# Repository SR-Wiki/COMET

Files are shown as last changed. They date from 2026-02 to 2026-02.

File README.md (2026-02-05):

# COMET
This repository includes files for COMET (Cortex-wide Observational Miniature Epifluorescence Technique)
**[[COMET Wiki](https://github.com/ChangliangGuo2/COMET/wiki)] [[Miniscope DAQ Software Wiki](https://github.com/Aharoni-Lab/Miniscope-DAQ-QT-Software/wiki)] [[Miniscope DAQ Firmware Wiki](https://github.com/Aharoni-Lab/Miniscope-DAQ-Cypress-firmware/wiki)]**

## Overview of COMET
<video width="100" height="50" src="https://github.com/user-attachments/assets/f9d4e9b6-175c-49de-b77d-f8bc424e642c"></video>
### Components
<div align=center>
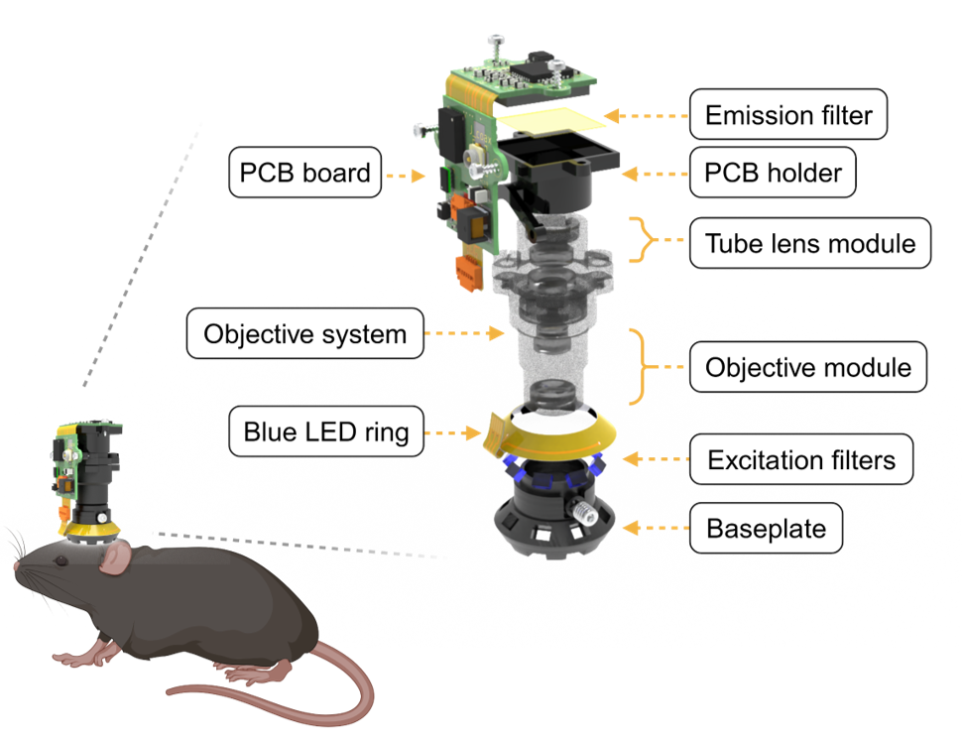
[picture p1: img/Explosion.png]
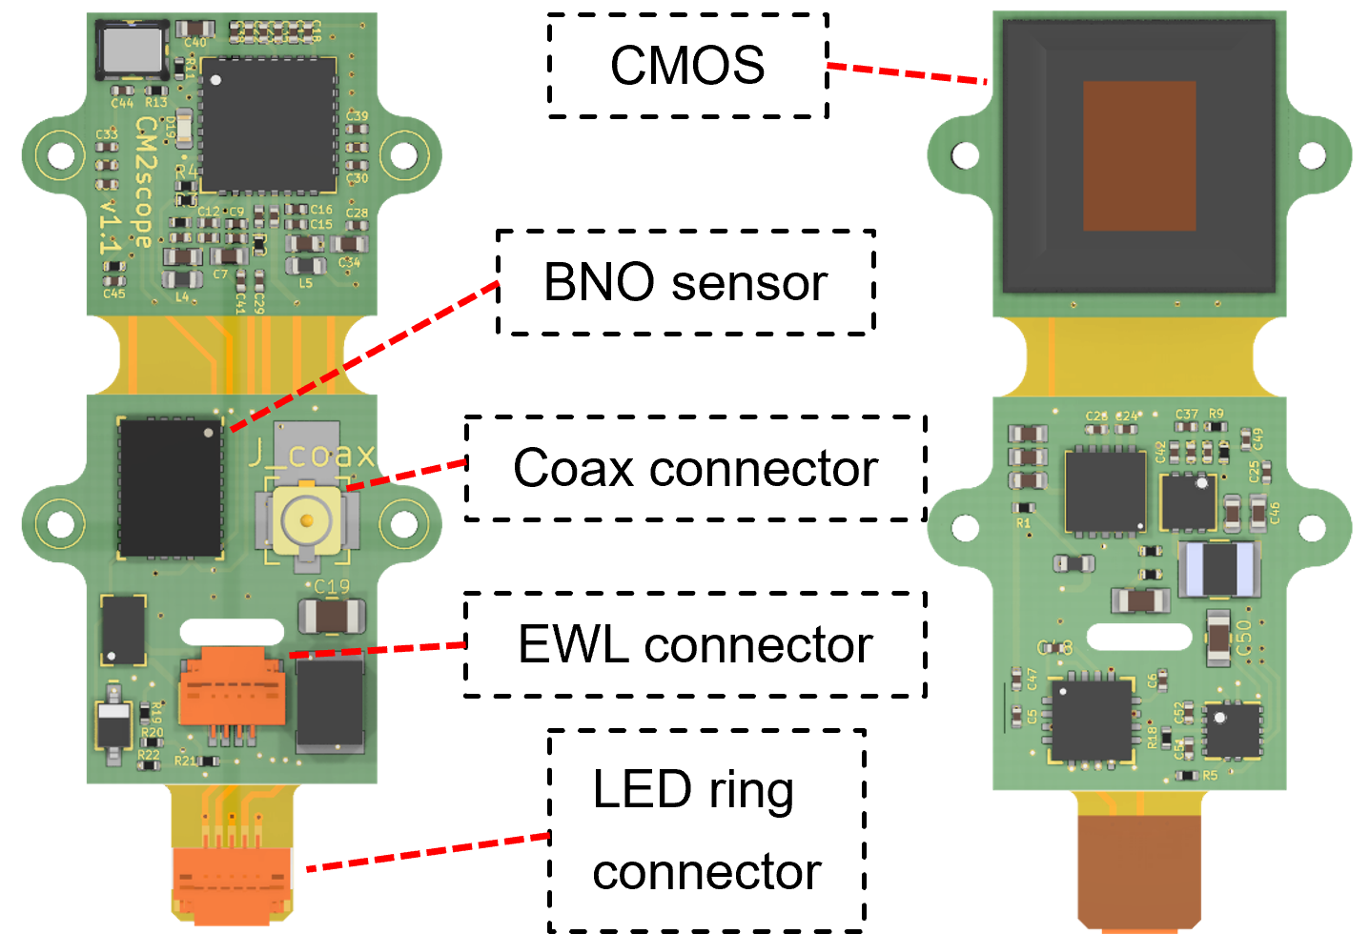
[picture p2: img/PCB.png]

</div>

### Specfications
- **Field of View**: up to 10-mm in diameter
- **Resolution**: single cell_ resolution
- **Working Distance**: ~5mm working distance
- **Illumination**: Optimized led ring excitation for even illuminiation across the field of view
- **Optics**: customized optical system for miniature abberations across the field of view
- **Photo-Bleaching**: _Low photo-bleaching_ even after _two hours of continuous imaging_
- **Weight**: 3.75 grams
- **Impact on Subjects**: Combined with intergrated active commutator(Torque-free),essentially there is _no impact on the free behavior_ of mice even during _two hours_ of continuous imaging
- **Orientation Sensor**: Absolute head orientation sensor
- **Focal Adjustment**: electronic focal adjustment(optional)
- **Imaging Performance**: _stable_ imaging performance even in the _electroshock_ paradigm and  _two hours_ of continuous imaging paradigm
<p dir="auto"><strong>All information, guides, and tutorials can be found on the <a href="https://github.com/ChangliangGuo2/COMET/wiki">COMET Wiki Page</a>.</strong></p>

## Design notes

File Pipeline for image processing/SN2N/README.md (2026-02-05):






<br>



 

<p>
<h1 align="center">SN<font color="#FF6600">2</font>N</h1>
<h5 align="center">Self-inspired learning to denoise for live-cell super-resolution microscopy.</h5>
<h6 align="right">v0.3.5</h6>
</p>

<br>

<p>

</p>
<br>

<br><br><br>

---

## About SN2N

<p>
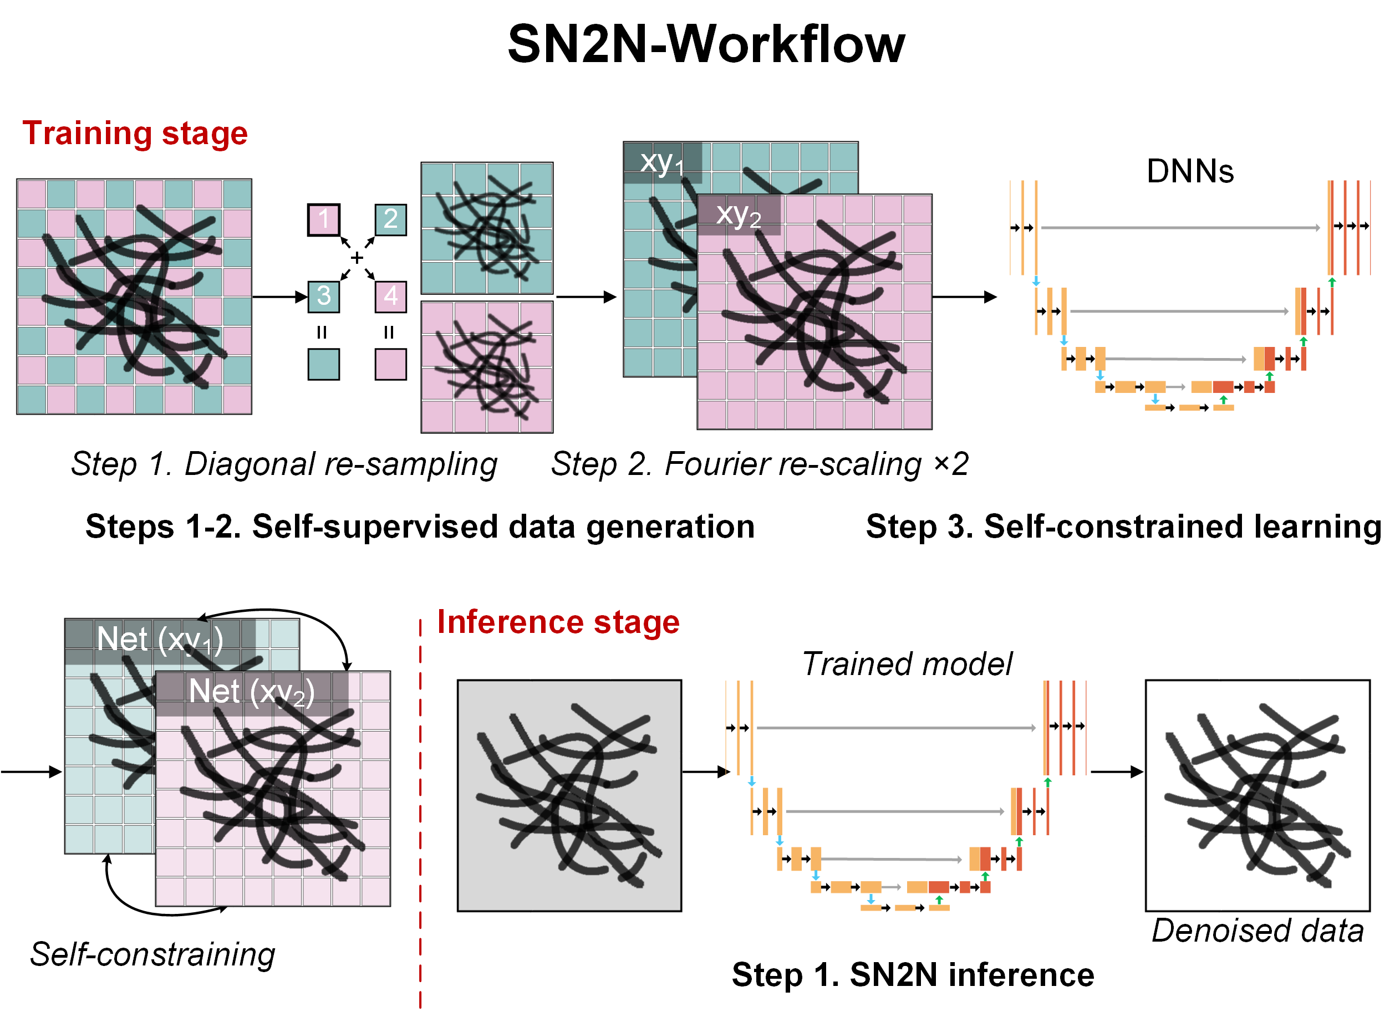
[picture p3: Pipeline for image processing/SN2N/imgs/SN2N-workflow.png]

</p>

SN2N is fully competitive with the supervised learning methods and overcomes the need for large dataset and clean ground-truth, and this is a version specifically for temporal data. **First**, self-supervised data are generated based on images' temporal redundancy, resampling along the T axis. **Second**,  a self-constrained learning process is used to enhance the performance and data-efficiency. **Finally**, a Patch2Patch data augmentation strategy (random patch transformations in multiple dimensions) is designed to further improve the data efficiency.

## 🔧 Installation

### Tested platform
  - Python = 3.7.6, Pytorch = 1.12.0 (`Win 10`, `128 GB RAM`, `NVIDIA RTX 4090 24 GB`, `CUDA 11.6`)

### Dependencies
  - Python >= 3.6
  - PyTorch >= 1.10

### Instruction

1. Alter the working directory.

    ```bash
    cd SN2N    
    ```

2. Create a virtual environment and install PyTorch and other dependencies. Please select the correct Pytorch version that matches your CUDA version from [https://pytorch.org/get-started/previous-versions/](https://pytorch.org/get-started/previous-versions/). 

    Users can set up the environment directly by installing the packages listed in the (**requirements.txt**) file. The packages required by the environment have also been uploaded to the requirements.

    ```bash
    $ conda create -n SN2N python=3.7.6
    $ conda activate SN2N
    
    $ pip install -r requirements.txt
    ```

### How to use?
The SN2N framework contains 3 main steps: self-supervised data generation, model training, and inference, which have been integrated into file SN2N_execute.py. 
```
python SN2N_execute.py --img_path "path/to/raw/data" --P2Pmode "1" --P2Pup "1" --BAmode "1" --SWsize "64" --sn2n_loss "1" --bs "32" --lr "2e-4" --epochs "100"      
```
To see how each part works, this [demo_notebook](./demo_SN2N.ipynb) might be helpful.

#### Parameters instructions

The key parameters are listed below. There are also other parameters that do not require user modification. For a more detailed instructions of parameter setting, please refer to the [official SN2N website](https://github.com/WeisongZhao/SN2N).

```
    -----Parameters------
    =====Important==========

    **Data Generation**
    img_path:
        Path of raw images to train.
    P2Pmode(0 ~ 3):
        Augmentation mode for Patch2Patch.
        0: NONE; 
        1: Direct interchange in t;
        2: Interchange in single frame;
        3: Interchange in multiple frame but in different regions;
        {default: 0}
    P2Pup:
        Increase the dataset to its (1 + P2Pup) times size.
        {default: 0}
    BAmode(0 ~ 2):
        Basic augmentation mode.
        0: NONE; 
        1: double the dataset with random rotate&flip;
        2: eightfold the dataset with random rotate&flip;
        {default: 0} 
    SWsize:
        Interval pixel of sliding window for generating image pathes.
        {default: 64}
    ------------------------------------------------------------------------
    **Model Training**
    sn2n_loss:
        Weight of self-constrained loss.
        {default: 1}
    bs:
        Training batch size.
        {default: 32}
    lr:
        Learning rate
        {default: 2e-4}.
    epochs:
        Total number of training epochs.
        {default: 100}.
    ------------------------------------------------------------------------
    Inference
    final_model:
        if only inference with the final model
        {default: True}.
        
    ======Other parameters do not require modification; ======
    
```

If you have a pretrained model, the inference stage can also be done by:
```
python inference.py --img_path "path/to/raw/data" --model_path "path/to/your/model.pth" --save_path "path/to/save/dir"
```

Several tip:
1. Considering training time, sometimes only parts of raw data might be put into the "raw data" folder.
2. Please ensure that "Users own path/data/raw_data/generated_data" is empty if training data haven't been generated.
3. The sn2n_loss is the most important paramter to finetune, and actually a tradeoff between noise-removal capability and over-smoothing, but a value of 1 will be OK most of the time.
4. Progress can be tracked by checking the validation results in "Users own path/data/raw_data/images/{your_model_name}/images, setting "final_model" to false in the inference stage. In this way, the best model can be manually chosen in case of overfitting (strong artifacts). Nonetheless, ovefitting may also indicate an inappropriate sn2n_loss value.

## &#x1F308; Resources:

- **Some fancy results and comparisons:** [Lab's website](https://weisongzhao.github.io/home/portfolio-4-col.html#SN2N)
- **Preprint:** [Liying Qu et al. Self-inspired learning to denoise for live-cell super-resolution microscopy, bioRxiv (2024).](https://doi.org/10.1101/2024.01.23.576521)
- **Detailed Instructions:** https://github.com/WeisongZhao/SN2N
- **Publication:** [Liying Qu et al. Self-inspired learning for denoising live-cell super-resolution microscopy, 21, 1895–1908, Nature Methods (2024)](https://www.nature.com/articles/s41592-024-02400-9).

## Open source [SN2N](https://github.com/WeisongZhao/SN2N)
This software and corresponding methods can only be used for **non-commercial** use, and they are under Open Data Commons Open Database License v1.0.

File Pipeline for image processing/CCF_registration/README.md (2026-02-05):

# Registering each extracted neuron to the CCF atlas
## Parameters：
- front_pos：cranial window Anterior edge to the brgma point _(unit:mm)_
- back_pos：cranial window Posterior edge to the brgma point _(unit:mm)_
- RSPd_MO_point： Displacement adjustment between the standard brain and the FOV of the image;example:[vertical_displacement，horizotal_displacement] _(unit:pixel)_
- angle：rotate angle, clockwise is negtive _(unit:°)_
- instrument_pixel_size：optical instrument pixel size _(unit:mm/pixel)_
- instrument_size：captured image size,example:[1944,1944] _(unit:pixel)_
## How to use cortical_mapping_CM2.m：
Fill in `front_pos`, `back_pos`, `instrument_pixel_size`   `instrument_size` parameters based on the actual surgical conditions and optical equipment parameters.
Then, initially set the endpoint after line 65, iteratively run the program and modify the `RSPd_MO_point` and `angle` parameters until the drawn brain map matches the actual data. 
Once the parameters are set, remove the breakpoint and run the program entirely.
## Result：
<div align=center>

</div>

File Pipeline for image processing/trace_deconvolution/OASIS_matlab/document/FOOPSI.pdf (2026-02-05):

# Brief summary of the deconvolution problem

A brief summary of denoising and deconvolving calcium imaging data using FOOPSI approaches.

# FOOPSI

A general form of the FOOPSI problem

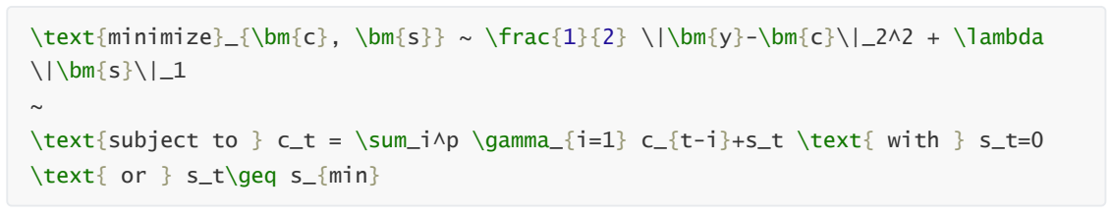
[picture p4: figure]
\text{ or } s_t\geq s_{min}

where $|\cdot|1$ means L-1 norm (http://mathworld.wolfram.com/L1-Norm.html) and $|\cdot|2$ means L-2 norm. (http://mathworld.wolfram.com/L2-Norm.html) $\bm{y}$ is the noisy raw calcium trace and $\bm{c}$ is the desired denoised trace. We use an auto-regressive (AR) $c_t = \sum_i^p \gamma{i=1} c{t-i}+s_t$ model to model $\bm{c}$ and the corresponding spiking activity $\bm{s}$. A more general model of $\bm{c}$ and $\bm{s}$ is $\bm{c} = \bm{s} \ast \bm{h}$, where $\ast$ means convolution. The convolution kernel $\bm{h}$ has a interpretation of calcium responses of a neuron after firing a spike.

The AR model is equivalent to special kernel $\bm{h}$. For example, AR-1 model ($p=1$) correspond to

and AR-2 ($p=2$) model correspond to

Details of these AR model can be found in the literatures [1][2][3].

# Different formulations of FOOPSI

We described the most general format of FOOPSI above. In practice, people use different formulations of FOOPSI for their own data. Here I brief summarize different formulations.

## original FOOPSI [1]

The original FOOPSI solves the following problem

where $\lambda$ has to be pre-specified by users and $\gamma$ needs to be estimated as well.

This formulation has the simplest format, but the parameter selection is a pain.

\text{minimize}_{\bm{c}, \bm{s}} ~ \frac{1}{2} \|\bm{y}-\bm{c}\|_2^2 + \lambda

\text{subject to } c_t = \sum_i^p \gamma_{i=1} c_{t-i}+s_t \text{ with } s_t=0

h(t) = \exp(-t/\tau)

h(t) = \exp(-t/\tau_d) - \exp(-t/\tau_r).

\text{minimize}_{\bm{c}, \bm{s}} ~ \frac{1}{2} \|\bm{y}-\bm{c}\|_2^2 + \lambda

\text{subject to } c_t = \sum_i \gamma_{i=1}^p c_{t-i}+s_t

## constrained FOOPSI [2]

This formulation is equivalent to solving a original FOOPSI problem except that it chooses $\lambda$ automatically by constraining the residual sum of squares (RSS) to be $\sigma^2T$, where $\sigma$ is the noise level and can be estimated from the raw data.

### thresholded FOOPSI [3]

Both the upper two approaches uses L-1 penalty to enforce the sparsity of the spiking signal $\bm{s}$. The advantage of these two formulations is that the optimization problems are convex. However, the estimated $\bm{s}$ usually contains many false positive spikes with small amplitudes, and these false positives affect the accurate estimation of the amplitudes of those true spikes. We can definitely remove them by thresholding $\hat{\bm{s}}$ in the downstream analysis, but it won't help with the estimation of true spikes in this step.

Thus a thresholded-FOOPSI was proposed to integrate the thresholding step into deconvolution by setting a hard threshold of spike size $s{min}$. This $s{min}$ is usually chosen as $3\sigma$, where the noise level $\sigma$ is estimated from the raw data.

This other automatic way of choosing $s_{min}$ is to use a similar approach of constrained FOOPSI by letting RSS equal to $\sigma^2T$.

## why OASIS

FAST and ONLINE

For the original FOOPSI and the constrained FOOPSI problem, they were usually solved using generic convex optimiation solvers to solve, which is slow and has to use the complete time series of $\bm{y}$ to optimize. OASIS is optimized for solving FOOPSI problems by utilizing the special structure of AR model. The algorithm is FAST and, more importantly, it allows ONLINE processing of the data.

As for the thresholded FOOPSI, it is not convex. Thus we don't have algorithm to solve this problem at the beginning. When OASIS was developed, we made very tiny changes to the code and it outputs reasonable good results. Also there is no guarantee on the global optimums, the results are usually good in both simulated data and real data.

Besides solving the above optimization problems, the implementation of OASIS also include supports for automatic optimizing parameters in those problems, such as $\lambda, \gamma$ and the baseline $b$.

\text{subject to } c_t = \sum_i \gamma_{i=1}^p c_{t-i}+s_t \text{ and } \|\bm{y}-

\text{subject to } c_t = \sum_i \gamma_{i=1}^p c_{t-i}+s_t \text{ with } s_t=0

## References

[1] Vogelstein, J.T., Packer, A.M., Machado, T.A., Sippy, T., Babadi, B., Yuste, R. and Paninski, L., 2010. Fast nonnegative deconvolution for spike train inference from population calcium
imaging. Journal of neurophysiology,104(6), pp.3691-3704.
[2] Pnevmatikakis, E.A., Soudry, D., Gao, Y., Machado, T.A., Merel, J., Pfau, D., Reardon, T., Mu, Y., Lacefield, C., Yang, W. and Ahrens, M., 2016. Simultaneous denoising, deconvolution, and demixing of calcium imaging data. Neuron, 89(2), pp.285-299.
[3] Friedrich, J., Zhou, P. and Paninski, L., 2017. Fast online deconvolution of calcium imaging data. PLoS computational biology, 13(3), p.e1005423.

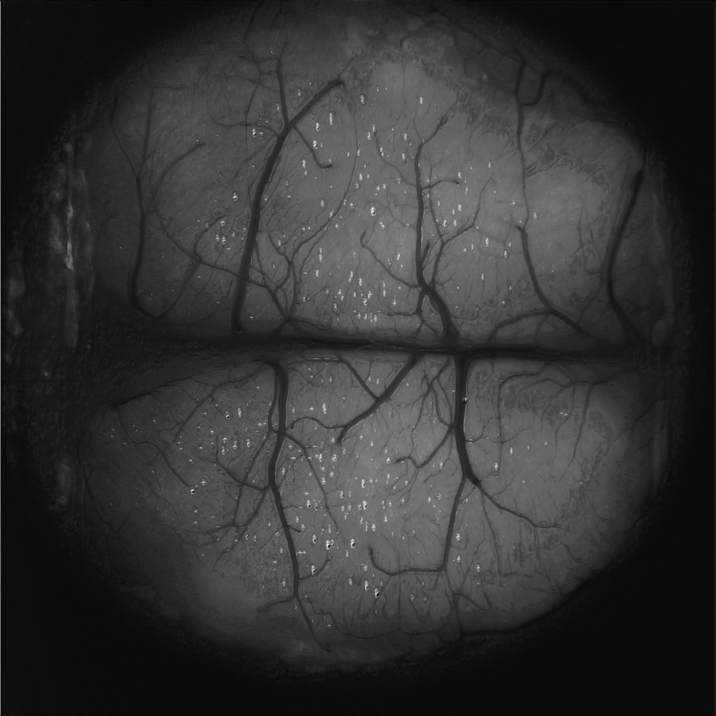
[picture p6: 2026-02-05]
Pipeline for image processing/SN2N/example/rawdata/images/Neuron__EPOCH50_BS64_LOSSconsis_1.50_LOSSsparse0.00_/images/epoch_49.tif

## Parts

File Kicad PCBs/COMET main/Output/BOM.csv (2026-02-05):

Item | Qty | Reference(s) | Value | Footprint | Description | Note
1 | 6 | C1, C2, C14, C20, C34, C40 | GRM155R60J106ME15D | .Capacitor:C_0402_1005Metric_L | CAP CER 10UF 6.3V X5R 0402 | 10uF
3 | 1 | C4 | GRM033R61C473KE84D | .Capacitor:C_0201_0603Metric_L | CAP CER 0.047UF 16V X5R 0201 | 0.047uF
4 | 4 | C5, C6, C47, C48 | GRM033R61A225ME47D | .Capacitor:C_0201_0603Metric_L | CAP CER 2.2UF 10V X5R 0201 | 2.2uF
5 | 3 | C7, C10, C46 | GRM155R60J475ME87D | .Capacitor:C_0402_1005Metric_L | CAP CER 4.7UF 6.3V X5R 0402 | 4.7uF
7 | 7 | C9, C12, C16, C18, C23, C42, C44 | GRM033R71A103KA01D | .Capacitor:C_0201_0603Metric_L | CAP CER 10000PF 10V X7R 0201 | 10nF
10 | 1 | C19 | GRM21BR61A476ME15L | .Capacitor:C_0805_2012Metric_L | CAP CER 47UF 10V X5R 0805 | 47uF
12 | 1 | C21 | GRM158C80G226ME01J | .Capacitor:C_0402_1005Metric_L |  | 22uF
13 | 7 | C13, C24, C25, C26, C28, C38, C45 | GRM033R61A105ME15D | .Capacitor:C_0201_0603Metric_L | CAP CER 1UF 10V X5R 0201 | 1uF
16 | 21 | C3, C8, C11, C15, C17, C22, C27, C29, C30, C31, C32, C33, C35, C36, C37, C39, C41, C43, C49, C51, C52 | GRM033R61A104ME15D | .Capacitor:C_0201_0603Metric_L | CAP CER 0.1UF 10V X5R 0201 | 0.1uF
23 | 1 | C50 | GRJ188R72A104KE11D | .Capacitor:C_0603_1608Metric_L | CAP CER 0.1UF 100V X7R 0603 | 100nF
26 | 1 | D18 | BAS316-TP | .Diode:SOD_323_250X125X110L30X32L | DIODE GEN PURP 100V 250MA SOD323
27 | 1 | D19 | LED 0402 | LED_SMD:LED_0402_1005Metric | LED RED 0402 SMD | red
28 | 1 | J1 | FH19C-5S-0.5SH(10) | .FH19C-4S-0.5SH(10):FH19C-5S-0.5SH(10)
29 | 1 | J4 | FH19C-4S-0.5SH(10) | .FH19C-4S-0.5SH(10):FH19C-4S-0.5SH(10)
31 | 1 | J_coax1 | U.FL-R-SMT-1(10) | .Connector:Coax_Conn_U.FL | CONN U.FL RCPT STR 50 OHM SMD
33 | 3 | L1, L4, L5 | BLM15HD102SN1D | Inductor_SMD:L_0402_1005Metric | FERRITE BEAD 1 KOHM 0402 1LN | 1kohm
34 | 1 | L2 | ADL3225V-470MT-TL000 | .Inductor:L_1210_3225Metric_L | FIXED IND 47UH 500MA 900 MOHM | 47uH
35 | 1 | L3 | LQM18PN3R3MGHD | .Inductor:L_0603_1608Metric_L | FIXED IND 3.3UH 1.05A 250 MOHM | 3.3uH
36 | 1 | L6 | LQM2HPN1R0MG0 | .Inductor:L_1008_2520Metric_L
37 | 1 | R1 | ERJ-1GNF1801C | .Resistor:R_0201_0603Metric_ERJ_L | RES SMD 1.8K OHM 1% 1/20W 0201 | 1.8k
38 | 1 | R2 | ERJ-1GNF49R9C | .Resistor:R_0201_0603Metric_ERJ_L | RES SMD 49.9 OHM 1% 1/20W 0201 | 49.9
39 | 4 | R3, R7, R9, R10 | ERJ-1GNF1022C | .Resistor:R_0201_0603Metric_ERJ_L | RES SMD 10.2K OHM 1% 1/20W 0201 | 10.2k
40 | 1 | R4 | ERJ-1GNF1003C | .Resistor:R_0201_0603Metric_ERJ_L | RES SMD 100K OHM 1% 1/20W 0201 | 100k
41 | 1 | R5 | 0402WGF6491TCE | .Resistor:R_0201_0603Metric_ERJ_L | RES SMD 10.2K OHM 1% 1/20W 0201 | 6.49k
44 | 1 | R12 | 1k | .Resistor:R_0201_0603Metric_ERJ_L | 1k | 1k
45 | 1 | R13 | 500 | .Resistor:R_0201_0603Metric_ERJ_L | 500 | 500
46 | 2 | R14, R15 | ERJ-1GNF3321C | .Resistor:R_0201_0603Metric_ERJ_L | RES SMD 3.32K OHM 1% 1/20W 0201 | 3.32k
47 | 1 | R18 | 0402WGF1962TCE | .Resistor:R_0201_0603Metric_ERJ_L | RES SMD 10.2K OHM 1% 1/20W 0201 | 19.6k
48 | 2 | R19, R21 | ERJ-1GNJ622C | .Resistor:R_0201_0603Metric_ERJ_L | RES SMD 6.2K OHM 5% 1/20W 0201 | 6.2k
49 | 2 | R20, R22 | ERJ-1GNF3741C | .Resistor:R_0201_0603Metric_ERJ_L | RES SMD 3.74K OHM 1% 1/20W 0201 | 3.74k
50 | 1 | U1 | DS90UB913ATRTVTQ1 | .Package_QFN:QFN_33_P50_500X500X80L40X24T310L | IC SER/DES 10-100MHZ FPD 32WQFN
51 | 1 | U2 | LTC3217EUD_TRPBF | Package_DFN_QFN:HVQFN-16-1EP_3x3mm_P0.5mm_EP1.5x1.5mm | \n600mA Low Noise Multi-LED Camera Light Charge Pumps\n
52 | 1 | U3 | SC189ZULTRT | .Package_SON:SON_7P50_200X200X57L35X24T170X80N
53 | 1 | U4 | NCV8154MW180280TBG | .Package_QFN:DFN10_3x3_11P50_300X300X100L40X24T250X180N
54 | 1 | U5 | BNO055 | Package_LGA:LGA-28_5.2x3.8mm_P0.5mm | IMU ACCEL/GYRO/MAG I2C 28LGA
55 | 1 | U6 | SG-210STF 66.6667ML3 | .Oscillator:OSC_CC250X200X80L70X75L | XTAL OSC XO 66.6667MHZ CMOS SMD
56 | 1 | U7 | MAX14574EWL+ | .Package_BGA:BGA_15_NP50_3X5_155X255X69B31N | 4-Channel, High-Voltage, Liquid Lens Driver
57 | 1 | U8 | MT9P031I12STM-DP | .Package_LCC:iLCC48P70_1000X1000X135L80X40N | SENSOR IMAGE 5MP MONO CMOS 48LCC
58 | 1 | U9 | TPL0102-100RUCR | .Package_QFN:QFN_14_P40_200X200X40L40X20L | IC DGT POT 100KOHM 256TAP 14QFN

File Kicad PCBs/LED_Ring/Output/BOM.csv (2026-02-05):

Item | Qty | Reference(s) | Value | Footprint | Description | Note
1 | 8 | D1, D2, D3, D4, D5, D6, D7, D8 | LXZ1-PB01 | LXZ1-PB01 | LED LUXEON Z BLUE 470NM SMD | Blue

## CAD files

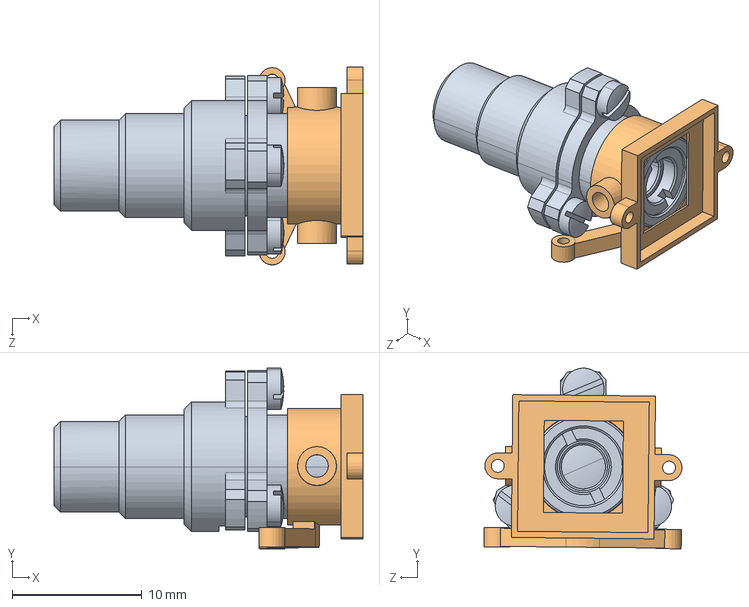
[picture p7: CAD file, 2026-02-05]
3D printed bodies/CMOS cover/装配体1.SLDASM
23.8 x 13.9 x 15.3 mm
Microscope-00.step
cmos外壳v5

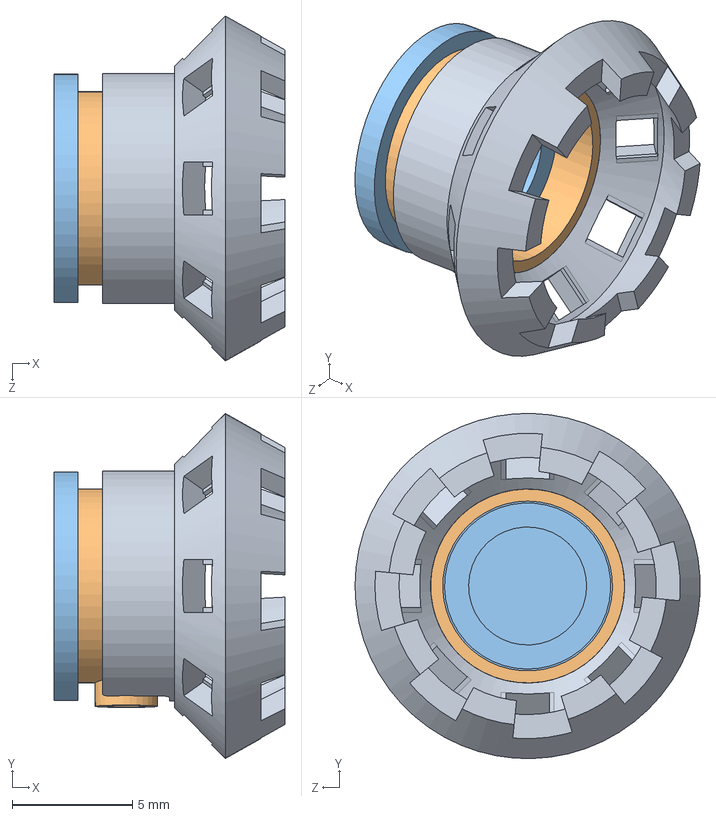
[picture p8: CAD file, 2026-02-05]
3D printed bodies/LED Ring Holder and Baseplate/45°/sldprt/LXZ1-PB01_num8_45°_6mm_v3加铝环/装配体1.SLDASM
9.59 x 14.3 x 14.3 mm
下面3D打印部分
铝环
protective_cap

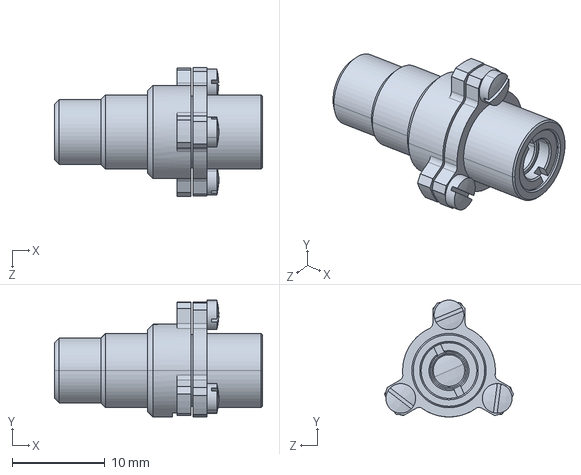
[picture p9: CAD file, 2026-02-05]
3D printed bodies/CMOS cover/Microscope-00.STEP
22.4 x 12.6 x 13.9 mm

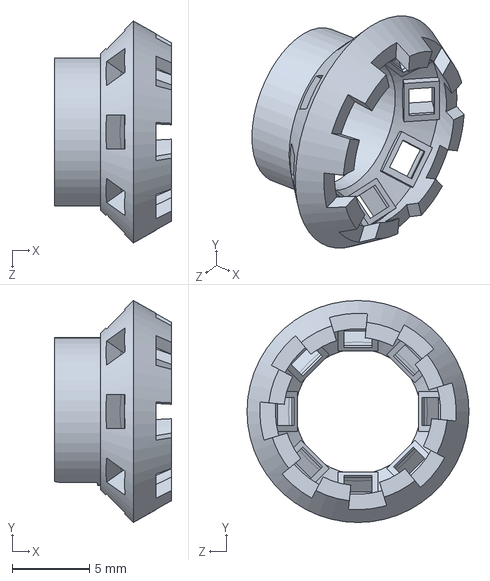
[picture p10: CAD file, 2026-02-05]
3D printed bodies/LED Ring Holder and Baseplate/45°/sldprt/LXZ1-PB01_num8_45°_6mm_v3加铝环/led_ring_illumination_加铝环_加深槽.SLDPRT
7.59 x 14.3 x 14.3 mm

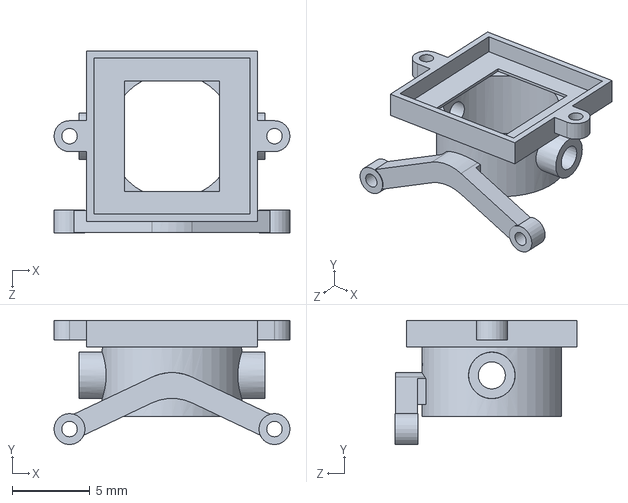
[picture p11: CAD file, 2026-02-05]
3D printed bodies/CMOS cover/cmos外壳v5.SLDPRT
15.2 x 8.00 x 11.8 mm

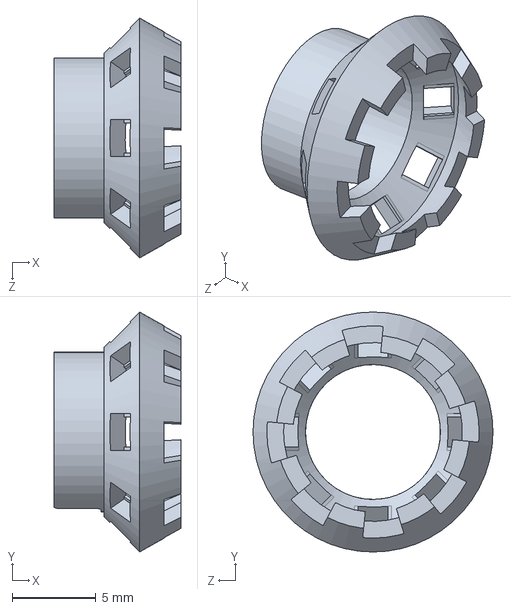
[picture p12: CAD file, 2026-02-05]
3D printed bodies/LED Ring Holder and Baseplate/45°/sldprt/LXZ1-PB01_num8_45°_6mm_v3加铝环/下面3D打印部分.SLDPRT
7.59 x 14.3 x 14.3 mm

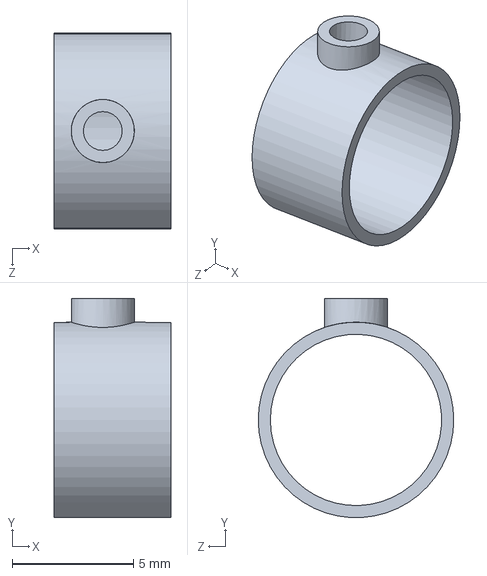
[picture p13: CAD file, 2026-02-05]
3D printed bodies/LED Ring Holder and Baseplate/45°/sldprt/LXZ1-PB01_num8_45°_6mm_v3加铝环/铝环.SLDPRT
4.80 x 9.02 x 8.05 mm

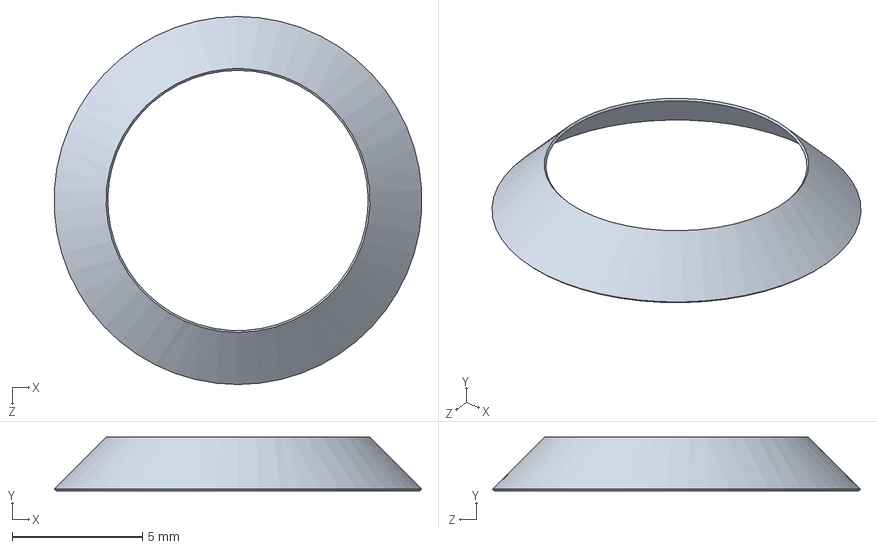
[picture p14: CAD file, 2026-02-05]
3D printed bodies/LED Ring Holder and Baseplate/45°/sldprt/LXZ1-PB01_num8_45°_6mm_v3加铝环/fpc.SLDPRT
14.1 x 2.07 x 14.1 mm

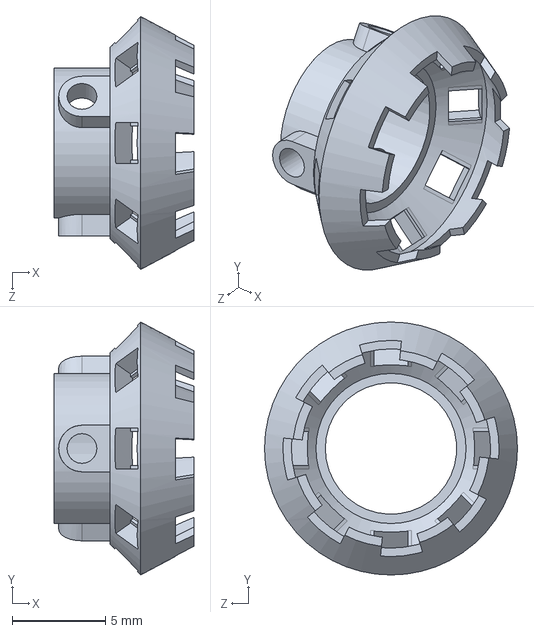
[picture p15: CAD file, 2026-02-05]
3D printed bodies/LED Ring Holder and Baseplate/45°/sldprt/LXZ1-PB01_num8_45°_6mm_v3加铝环/LXZ1-PB01_num8_45°_6mm_v3加铝环.SLDPRT
7.51 x 13.6 x 13.6 mm

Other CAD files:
3D printed bodies/CMOS cover/cmos外壳v5.STL

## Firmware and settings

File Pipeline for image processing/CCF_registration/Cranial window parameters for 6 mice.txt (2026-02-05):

AR93    Bregma至前沿 3.0mm，Bregma至后沿 4.5mm
AR94    Bregma至前沿 3.0mm，Bregma至后沿 4.4mm
AR367   Bregma至前沿 3.0mm，Bregma至后沿 4.8mm
AR369   Bregma至前沿 3.0mm，Bregma至后沿 5.0mm
AR370   Bregma至前沿 2.8mm，Bregma至后沿 5.0mm
AR371   Bregma至前沿 3.0mm，Bregma至后沿 4.8mm

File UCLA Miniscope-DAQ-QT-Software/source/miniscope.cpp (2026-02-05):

#include "miniscope.h"
#include "newquickview.h"
#include "videodisplay.h"
#include "videodevice.h"

#include <QQuickView>
#include <QQuickItem>
#include <QSemaphore>
#include <QObject>
#include <QTimer>
#include <QAtomicInt>
#include <QJsonObject>
#include <QJsonDocument>
#include <QJsonArray>
#include <QQmlApplicationEngine>
#include <QVector>
#include <QString>
#include <QtMath>
#include <QSerialPort>
#include <QSerialPortInfo>
#include <cmath>
#include <QtGlobal>



Miniscope::Miniscope(QObject *parent, QJsonObject ucDevice, qint64 softwareStartTime) :
    VideoDevice(parent, ucDevice, softwareStartTime),
    baselineFrameBufWritePos(0),
    baselinePreviousTimeStamp(0),
    m_displatState("Raw"),
    m_softwareStartTime(softwareStartTime)
{

    // --------------------

    // For Neuron Trace Display
    m_numTraces = 0;
    m_traceLastValueIdx = 0;
    // --------------------

    m_ucDevice = ucDevice; // hold user config for this device
    m_cDevice = getDeviceConfig(m_ucDevice["deviceType"].toString());

//    QObject::connect(this, &VideoDevice::displayCreated, this, &Miniscope::displayHasBeenCreated);
//    QObject::connect(this, &Miniscope::displayCreated, this, &Miniscope::displayHasBeenCreated);

}
void Miniscope::setupDisplayObjectPointers()
{
    // display object can only be accessed after backend call createView()
    rootDisplayObject = getRootDisplayObject();
    if (getHeadOrienataionStreamState())
        bnoDisplay = getRootDisplayChild("bno");
    QObject* temp = getRootDisplayChild("addTraceRoi");
    temp->setProperty("enabled", getTraceDisplayStatus());
    vidDisplay = getVideoDisplay();
}
void Miniscope::handleDFFSwitchChange(bool checked)
{
    qDebug() << "Switch" << checked;
    if (checked)
        m_displatState = "dFF";
    else
        m_displatState = "Raw";
}

void Miniscope::handleAddNewTraceROI(int leftEdge, int topEdge, int width, int height)
{
    double windowScale = m_ucDevice["windowScale"].toDouble(1);
    if (m_numTraces < NUM_MAX_NEURON_TRACES) {

//        qDebug() << leftEdge << topEdge << width << height;
        m_traceROIs[m_numTraces][0] = leftEdge/windowScale;
        m_traceROIs[m_numTraces][1] = topEdge/windowScale;
        m_traceROIs[m_numTraces][2] = width/windowScale;
        m_traceROIs[m_numTraces][3] = height/windowScale;


        m_traceColors[m_numTraces][0] = ((float)m_numTraces * 1.2 + 1)/4.0f;
        m_traceColors[m_numTraces][0] -= floor(m_traceColors[m_numTraces][0]);
        m_traceColors[m_numTraces][1] = -2.0f;
        m_traceColors[m_numTraces][2] = -2.0f;

        m_traceDisplayBufNum[m_numTraces] = 1;
        m_traceNumDataInBuf[m_numTraces][0] = 0;
        m_traceNumDataInBuf[m_numTraces][1] = 0;

        emit addTraceDisplay("Neuron" + QString::number(m_numTraces),
                             m_traceColors[m_numTraces],
                             1.0/255.0f,
                             "px",
                             false,
                             &m_traceDisplayBufNum[m_numTraces],
                             m_traceNumDataInBuf[m_numTraces],
                             TRACE_DISPLAY_BUFFER_SIZE,
                             m_traceDisplayT[m_numTraces][0],
                             m_traceDisplayY[m_numTraces][0]);

        // TODO: Must be a better way to append QVariant in qml
        QList<double> tempProp;
        QVariant varParams;

        tempProp = qvariant_cast< QList<double> >(vidDisplay->property("traceROIx"));
        tempProp.append(leftEdge);
        varParams.setValue<QList<double>>( tempProp );
        vidDisplay->setProperty("traceROIx", varParams);

        tempProp = qvariant_cast< QList<double> >(vidDisplay->property("traceROIy"));
        tempProp.append(topEdge);
        varParams.setValue<QList<double>>( tempProp );
        vidDisplay->setProperty("traceROIy", varParams);

        tempProp = qvariant_cast< QList<double> >(vidDisplay->property("traceROIw"));
        tempProp.append(width);
        varParams.setValue<QList<double>>( tempProp );
        vidDisplay->setProperty("traceROIw", varParams);

        tempProp = qvariant_cast< QList<double> >(vidDisplay->property("traceROIh"));
        tempProp.append(height);
        varParams.setValue<QList<double>>( tempProp );
        vidDisplay->setProperty("traceROIh", varParams);

        tempProp = qvariant_cast< QList<double> >(vidDisplay->property("traceColor"));
        tempProp.append(m_traceColors[m_numTraces][0]);
        varParams.setValue<QList<double>>( tempProp );
        vidDisplay->setProperty("traceColor", varParams);


        m_numTraces++;

    }
}


void Miniscope::handleNewDisplayFrame(qint64 timeStamp, cv::Mat frame, int bufIdx, VideoDisplay *vidDisp)
{
    QImage tempFrame2;
    cv::Mat tempFrame, tempMat1, tempMat2;
    float traceMean = 0;

//    for (int i=0; i < m_numTraces; i++) {
//        frame.at<uint8_t>(m_traceROIs[i][1],m_traceROIs[i][0]) = 255;
//        frame.at<uint8_t>(m_traceROIs[i][1] + m_traceROIs[i][3],m_traceROIs[i][0] + m_traceROIs[i][2]) = 255;
//    }

    // TODO: Think about where color to gray and vise versa should take place.
    if (frame.channels() == 1) {
        cv::cvtColor(frame, tempFrame, cv::COLOR_GRAY2BGR);
        tempFrame2 = QImage(tempFrame.data, tempFrame.cols, tempFrame.rows, tempFrame.step, QImage::Format_RGB888);
    }
    else
        tempFrame2 = QImage(frame.data, frame.cols, frame.rows, frame.step, QImage::Format_RGB888);

    // Generate moving average baseline frame
    if ((timeStamp - baselinePreviousTimeStamp) > 50) {
        // update baseline frame buffer every ~500ms
        tempMat1 = frame.clone();
        tempMat1.convertTo(tempMat1, CV_32F);
        tempMat1 = tempMat1/(BASELINE_FRAME_BUFFER_SIZE);
        if (baselineFrameBufWritePos == 0) {
            baselineFrame = tempMat1;
        }
        else if (baselineFrameBufWritePos < BASELINE_FRAME_BUFFER_SIZE) {
            baselineFrame += tempMat1;
        }
        else {
            baselineFrame += tempMat1;
            baselineFrame -= baselineFrameBuffer[baselineFrameBufWritePos%BASELINE_FRAME_BUFFER_SIZE];
        }
        baselineFrameBuffer[baselineFrameBufWritePos % BASELINE_FRAME_BUFFER_SIZE] = tempMat1.clone();
        baselinePreviousTimeStamp = timeStamp;
        baselineFrameBufWritePos++;
    }

    if (m_displatState == "Raw") {
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
